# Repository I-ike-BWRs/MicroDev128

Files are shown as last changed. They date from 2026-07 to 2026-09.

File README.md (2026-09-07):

### *Thank You to PCBWay for sponsoring this project! To see more look up the "Sponsorship Section"*

---

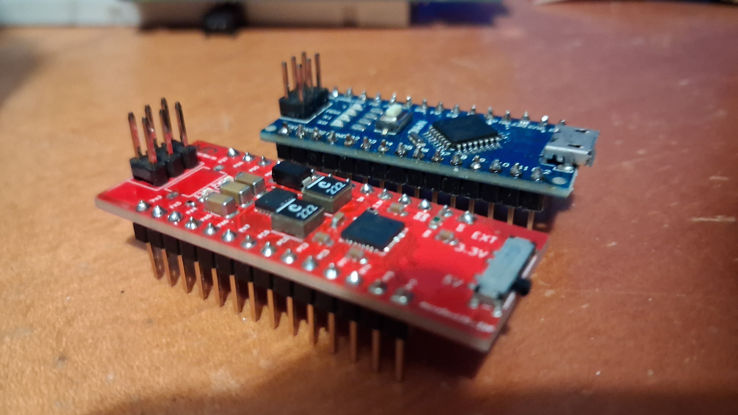
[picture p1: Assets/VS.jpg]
Project Image

# MicroDev128-32P
## A high-power development/prototyping board with MVIO. 

Based on the AVR128DB32. 

The MicroDev128-32P is open-source development board with a high-power voltage regulator with up to 2A continous, Multi-voltage IO - which allows PortC to run on a different voltage than the rest of the board - elimenating the need for voltage level shifters. The MicroDev128-32P aims to be better price to performance ratio than a tradition Arduino Nano. To view the Schematics you can go into the Kicad files folder. All files were made on KiCad 10.04 and should import without other dependencies. The 3D models are all included in the folder. 

**Key Specifications:**
- Up to 2A continuos on both power lines, 3.3v and 5v with up to 36VDC input
- Arduino Nano sized footprint, allowing it to easily be plugged into breadboards
- 128kB Flash, 16kB SRAM, and 512B
- Has with internal clock adjustable up to 24MHz max
- Built in TVS and 5A fuse
- UPDI Header for easy programing

## Documentation

For Documentation see the MicroDev128 Docs repository. 
[Link to Documents](https://github.com/ILikeBWRs/MicroDev128-Documentation)

---

## Images
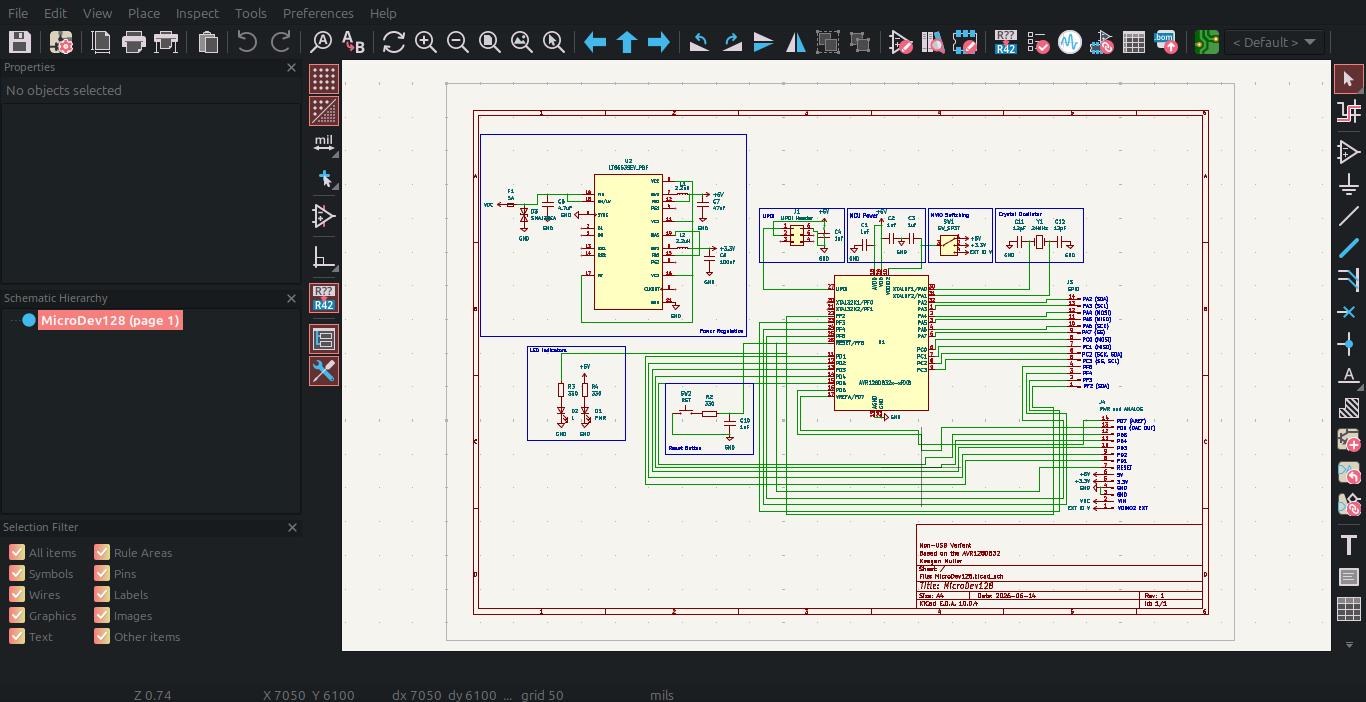
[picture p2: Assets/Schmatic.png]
Schematic

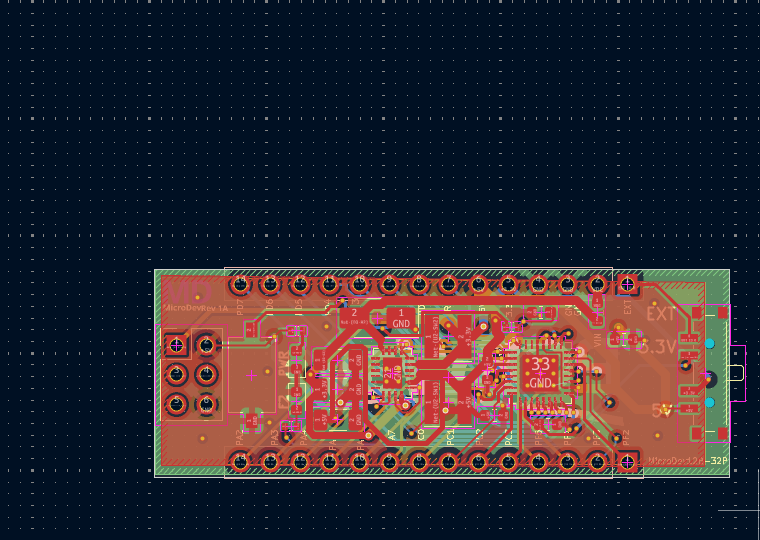
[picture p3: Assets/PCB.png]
PCB Layout

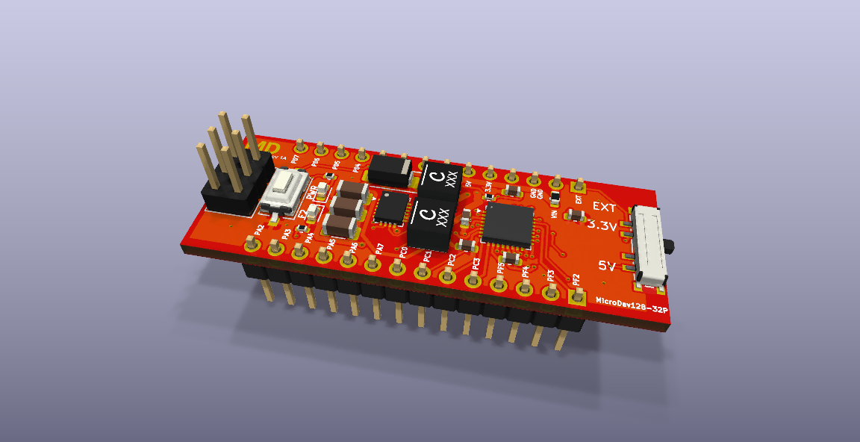
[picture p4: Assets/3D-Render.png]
3D Render


---

## Sponsorship
PCBway Logo
[PCBWay](https://pcbway.com) is a professional manufacturing service that offers PCB fabrication, PCB assembly, CNC machining, sheet metal fabrication, injection molding, and high-quality 3D printing services. They support a wide range of materials, including stainless steel, aluminum, titanium, and engineering plastics, making them suitable for prototype and production projects.
For my project they gave me five indivdual PCBs of outstanding surface quality. They surface was flat and smooth - with a perfect ENIG coating - with the corners rounded and deburred. The end application of this project is a Microcontroller board, suitable to be used in many situations. To see how easy their ordering procsess is go to the ordering section. 

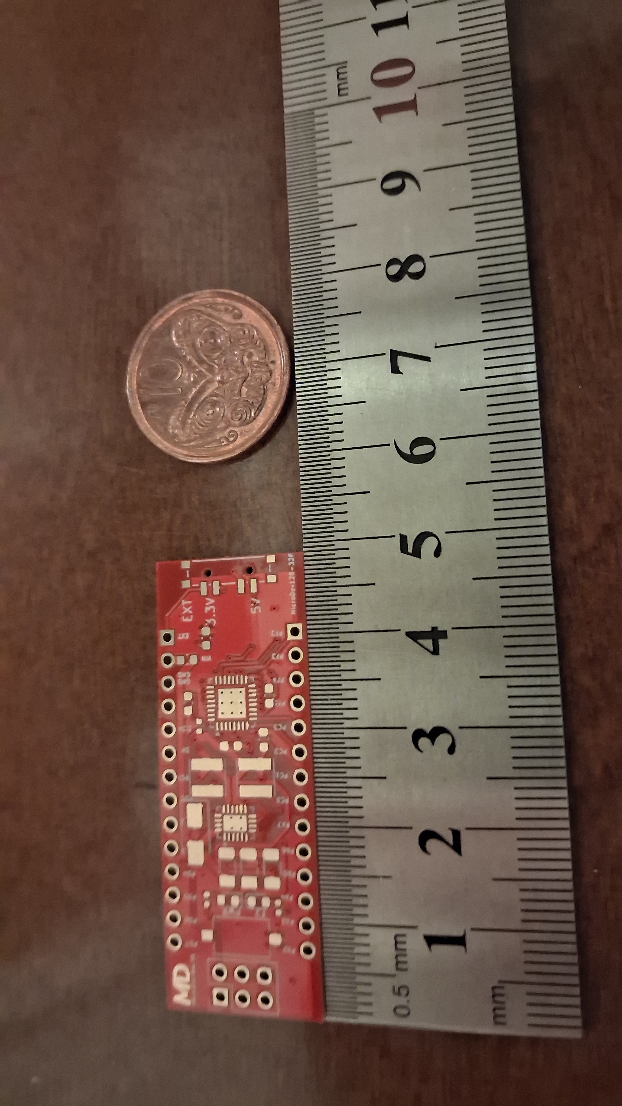
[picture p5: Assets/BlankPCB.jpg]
PCB


## Samples

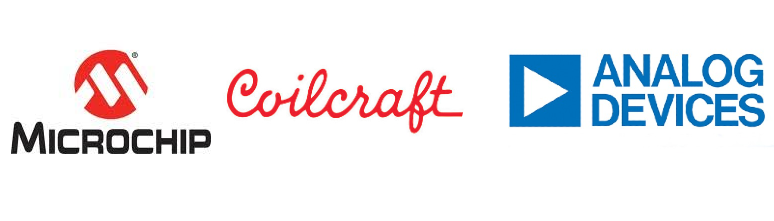
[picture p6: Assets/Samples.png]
Samples Companys


A big thank you to the sample programs of the following manufactures:
 - Microchip Technology
 - Analog Devices
 - Coilcraft
 - Würth Elektronik

---

## Ordering

To order your own you have a few ways:

**1. Order PCBs and assemble them yourself**

*You will need a hotplate for solder reflow and solder paste. May be cheaper but harder to do!*

Upload the Gebers at:
/MicroDev128-32P Production Files
   /Gebers.zip
Go to PCBWay's online ordering page and upload the gebers. Make sure it says 4-layers. Set it to ENIG, and set the solder mask to any colour you want. The rest of the default settings will be fine. Hit order or add stencil if you need one. It's that easy!

Next in the same folder find the BOM.csv and order the parts from your favorite part distributor. 
To lay out components once they turn up you can use the KiCad PCB layout. A dedicated image for this step will come later.

**2. Use PCBWay's PCBA service and get them shipped assembled**

Upload the Gebers at:

/Production Files

   /Gebers.zip
   
Go to your PCB and upload the gebers. Make sure it says 4-layers. Set it to ENIG, and set the solder mask to any colour you want. The default settings will be fine.
Then upload the BOM.csv and CPL.csv to the page. Then check if they in stock. (You may need to pre-order some parts!)
The check component orientation - it has a tendency to flip the LT8653S by 90 degrees. 
Then pay and let PCBWay's professional automated factory ship them fully assembled, right to your door!

## For more check out my stardance project page: -[Stardance Hackclub](https://stardance.hackclub.com/projects/6131)

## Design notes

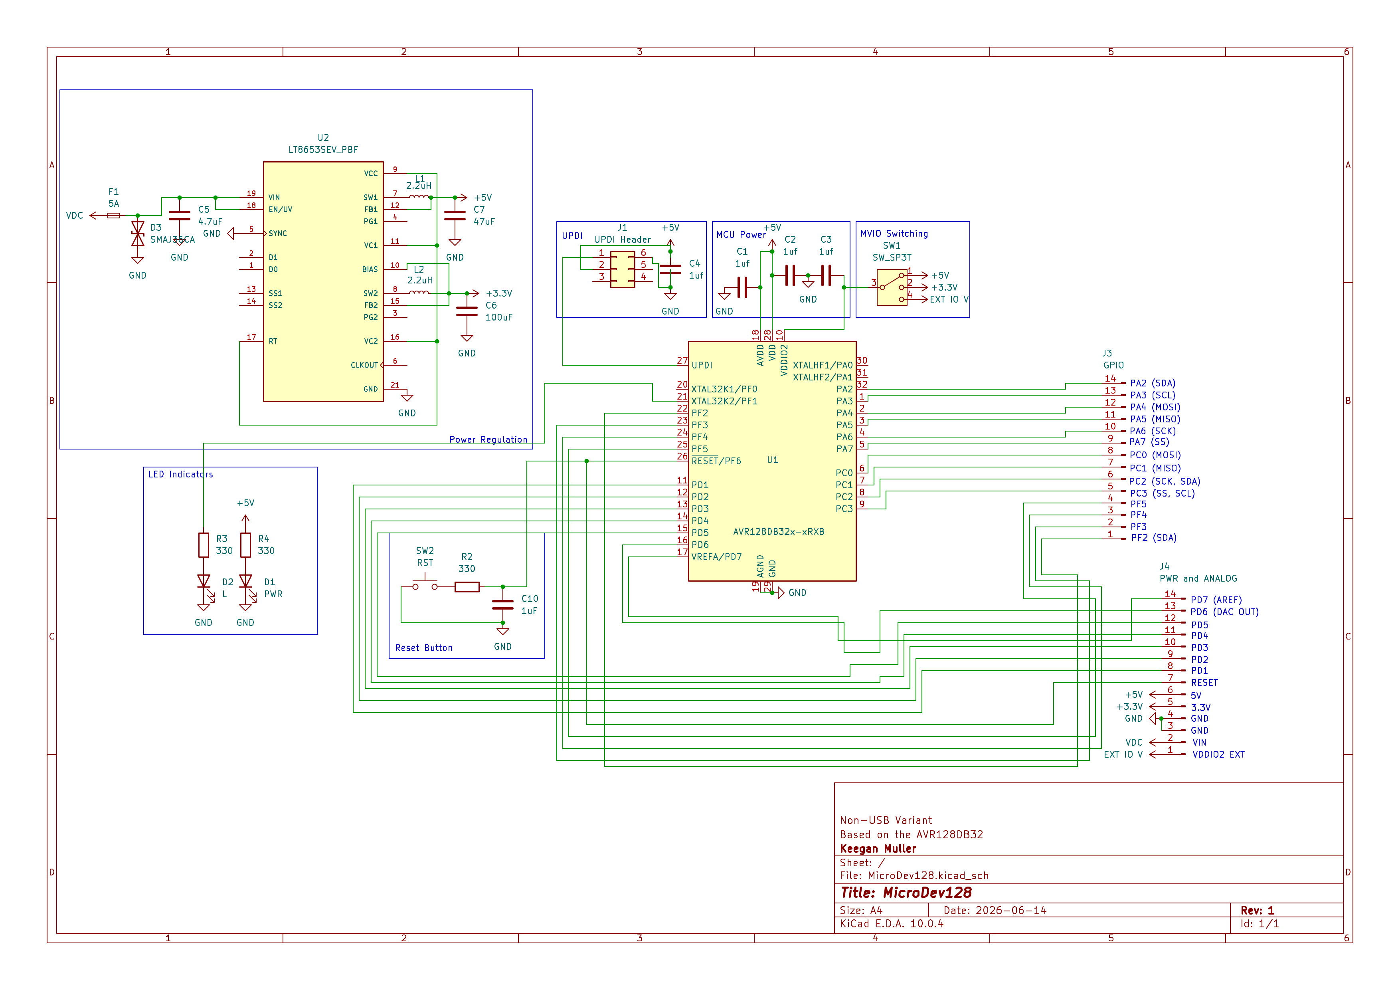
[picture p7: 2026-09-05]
Schematic.png

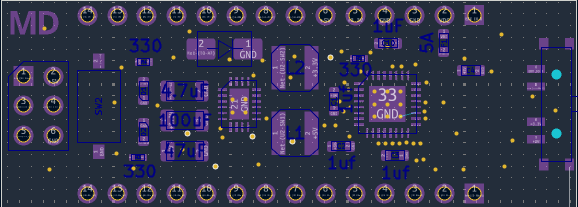
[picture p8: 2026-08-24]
MicroDev128-32P Production Files/Part Placement.png

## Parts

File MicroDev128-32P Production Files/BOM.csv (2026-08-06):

Reference | Value | Datasheet | Footprint | Qty | DNP
C1,C2,C3,C4 | 1uf |  | Capacitor_SMD:C_0603_1608Metric | 4
C5 | 4.7uF |  | Capacitor_SMD:C_1206_3216Metric | 1
C6 | 100uF |  | Capacitor_SMD:C_1206_3216Metric | 1
C7 | 47uF |  | Capacitor_SMD:C_1206_3216Metric | 1
C10 | 1uF |  | Capacitor_SMD:C_0603_1608Metric | 1
D1 | PWR |  | LED_SMD:LED_0603_1608Metric | 1
D2 | L |  | LED_SMD:LED_0603_1608Metric | 1
D3 | SMAJ36CA |  | Diode_SMD:D_SMA | 1
F1 | 5A |  | Fuse:Fuse_0603_1608Metric | 1
J1 | UPDI Header |  | Connector_PinHeader_2.54mm:PinHeader_2x03_P2.54mm_Vertical | 1
J3 | GPIO |  | Connector_PinHeader_2.54mm:PinHeader_1x14_P2.54mm_Vertical | 1
J4 | PWR and ANALOG |  | Connector_PinHeader_2.54mm:PinHeader_1x14_P2.54mm_Vertical | 1
L1,L2 | 2.2uH |  | Inductor_SMD:L_Taiyo-Yuden_NR-40xx | 2
R2,R3,R4 | 330 |  | Resistor_SMD:R_0402_1005Metric | 3
SW1 | SW_SP3T |  | Button_Switch_SMD:SW_SP3T_PCM13 | 1
SW2 | RST |  | Button_Switch_SMD:SW_Tactile_SPST_NO_Straight_CK_PTS636Sx25SMTRLFS | 1
U1 | AVR128DB32x-xRXB | https://ww1.microchip.com/downloads/en/DeviceDoc/AVR128DB28-32-48-64-DataSheet-DS40002247A.pdf | Package_DFN_QFN:QFN-32-1EP_5x5mm_P0.5mm_EP3.1x3.1mm | 1
U2 | LT8653SEV_PBF |  | Package_DFN_QFN:QFN-20-1EP_3x4mm_P0.5mm_EP1.65x2.65mm | 1

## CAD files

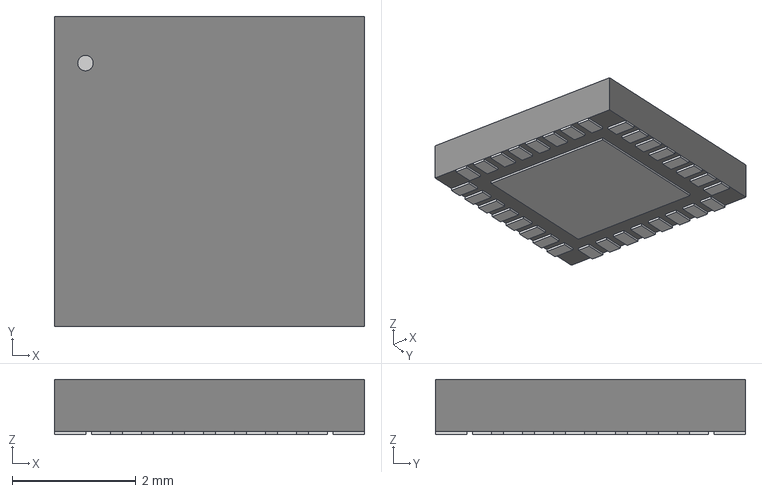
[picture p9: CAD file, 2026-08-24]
KiCad Files/3D Models/VQFN32_RXB_MCH.step
5.00 x 5.00 x 0.892 mm

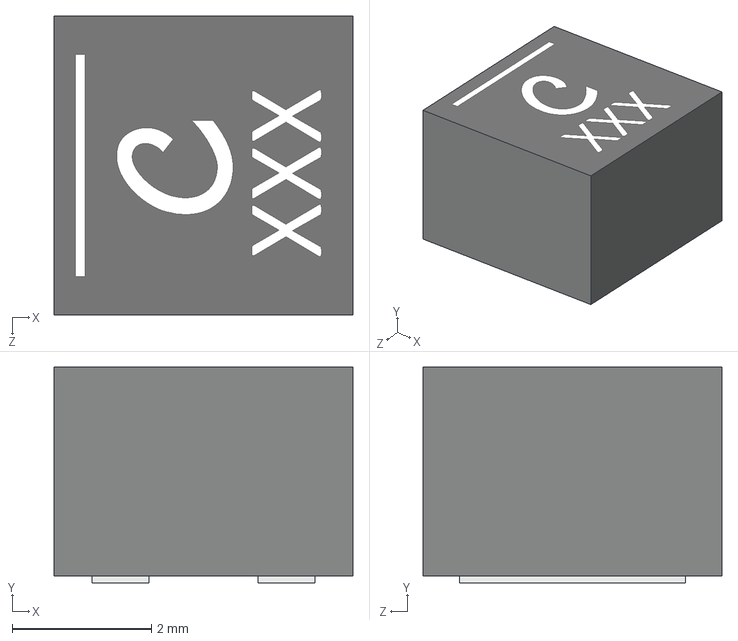
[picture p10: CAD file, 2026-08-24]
KiCad Files/3D Models/XGL4030.STEP
4.30 x 3.10 x 4.30 mm

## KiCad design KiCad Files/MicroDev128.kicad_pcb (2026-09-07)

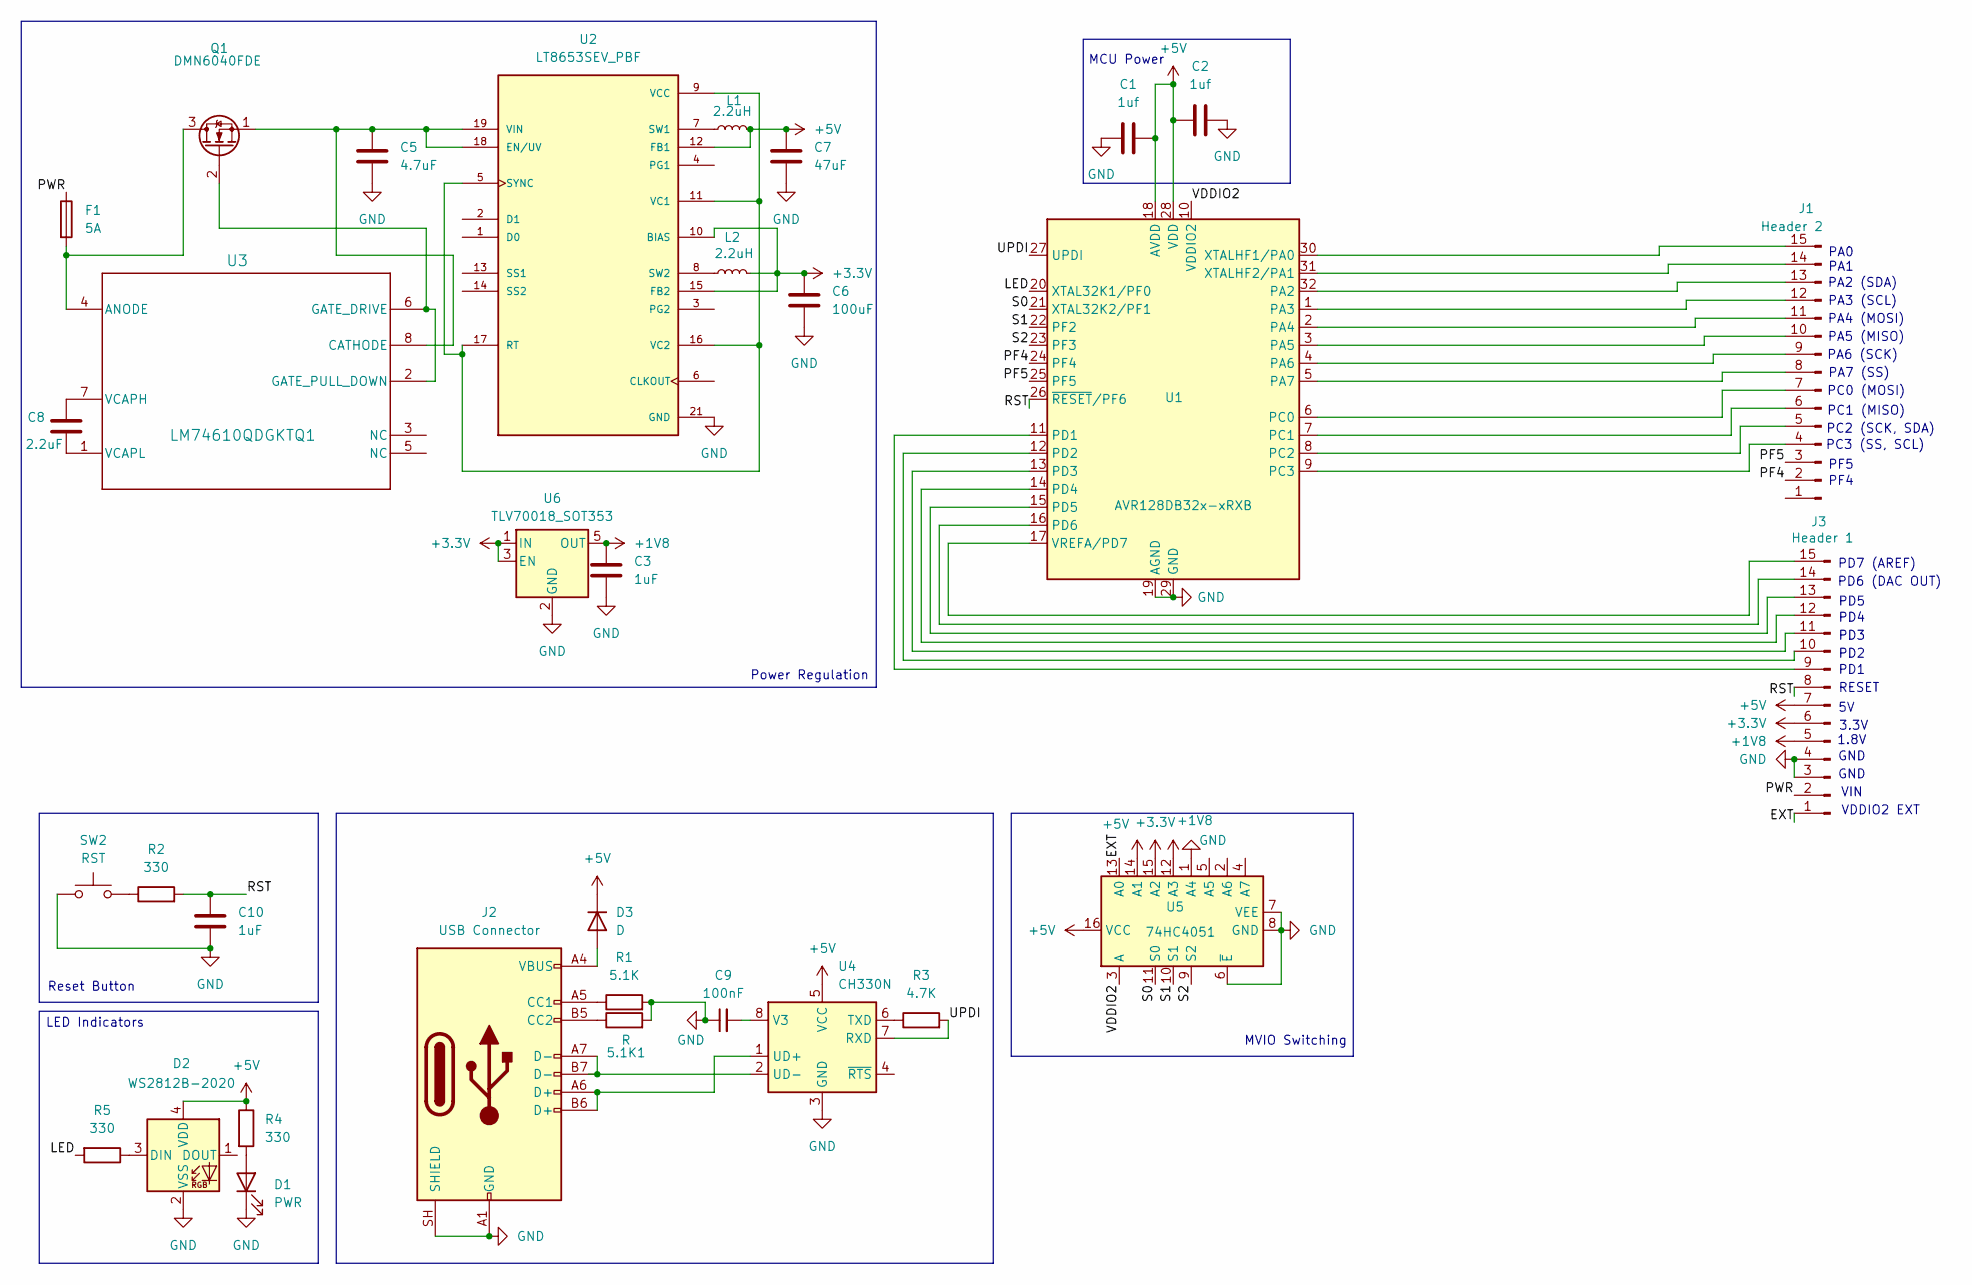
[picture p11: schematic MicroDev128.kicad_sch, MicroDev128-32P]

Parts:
5.1K1: R; R_0402_1005Metric
C1, C2: 1uf; C_0402_1005Metric
C3: 1uF; C_0402_1005Metric
C5: 4.7uF; C_1206_3216Metric
C6: 100uF; C_1206_3216Metric
C7: 47uF; C_1206_3216Metric
C8: 2.2uF; C_0402_1005Metric
C9: 100nF; C_0402_1005Metric
C10: 1uF; C_0603_1608Metric
D1: PWR; LED_0603_1608Metric
D2: WS2812B-2020; LED_WS2812B-2020_PLCC4_2.0x2.0mm
D3: D; D_SOD-323
F1: 5A; Fuse_0603_1608Metric
J1: Header 2; PinHeader_1x15_P2.54mm_Vertical
J2: USB Connector; USB_C_Receptacle_HRO_TYPE-C-31-M-12
J3: Header 1; PinHeader_1x15_P2.54mm_Vertical
L1, L2: 2.2uH; L_Taiyo-Yuden_NR-40xx
Q1: DMN6040FDE; DFN-6-1EP_2x2mm_P0.65mm_EP1.01x1.7mm
R1: 5.1K; R_0402_1005Metric
R2, R4, R5: 330; R_0402_1005Metric
R3: 4.7K; R_0402_1005Metric
SW2: RST; SW_Tactile_SPST_NO_Straight_CK_PTS636Sx25SMTRLFS
U1: AVR128DB32x-xRXB; QFN-32-1EP_5x5mm_P0.5mm_EP3.1x3.1mm
U2: LT8653SEV_PBF; QFN-20-1EP_3x4mm_P0.5mm_EP1.65x2.65mm; PARTREV B
U3: LM74610QDGKTQ1; VSSOP-8_3x3mm_P0.65mm
U4: CH330N; SOIC-8_3.9x4.9mm_P1.27mm
U5: 74HC4051; DHVQFN-16-1EP_2.5x3.5mm_P0.5mm_EP1x2mm
U6: TLV70018_SOT353; SOT-353_SC-70-5

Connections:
+1V8: C3.1, J3.5, U5.12 (A3), U6.5 (OUT)
+3.3V: C6.1, J3.6, L2.2, U2.10 (BIAS), U2.15 (FB2), U5.15 (A2), U6.1 (IN), U6.3 (EN)
+5V: C1.2, C2.1, C7.1, D2.4 (VDD), D3.1 (K), J3.7, L1.2, R4.1, U1.18 (AVDD), U1.28 (VDD), U2.12 (FB1), U4.5 (VCC), U5.14 (A1), U5.16 (VCC)
/EXT: J3.1, U5.13 (A0)
/LED: R5.2, U1.20 (XTAL32K1/PF0)
/PF4: J1.2, U1.24 (PF4)
/PF5: J1.3, U1.25 (PF5)
/PWR: F1.1, J3.2
/RST: C10.1, J3.8, R2.2, U1.26 (~RESET/PF6)
/S0: U1.21 (XTAL32K2/PF1), U5.11 (S0)
/S1: U1.22 (PF2), U5.10 (S1)
/S2: U1.23 (PF3), U5.9 (S2)
/UPDI: R3.2, U1.27 (UPDI), U4.7 (RXD)
/VDDIO2: U1.10 (VDDIO2), U5.3 (A)
GND: 5.1K1.2, C1.1, C2.2, C3.2, C5.2, C6.2, C7.2, C9.1, C10.2, D1.1 (K), D2.2 (VSS), J2.A1 (GND), J2.A12 (GND), J2.B1 (GND), J2.B12 (GND), J2.SH (SHIELD), J3.3, J3.4, R1.2, SW2.1, U1.19 (AGND), U1.29 (GND), U1.33 (GND), U2.21 (GND), U4.3 (GND), U5.1 (A4), U5.6 (~E), U5.7 (VEE), U5.8 (GND), U6.2 (GND)
unnamed: D1.2 (A), R4.2
unnamed: D2.3 (DIN), R5.1
unnamed: D3.2 (A), J2.A4 (VBUS), J2.A9 (VBUS), J2.B4 (VBUS), J2.B9 (VBUS)
unnamed: J1.4, U1.9 (PC3)
unnamed: J1.5, U1.8 (PC2)
unnamed: J1.6, U1.7 (PC1)
unnamed: J1.7, U1.6 (PC0)
unnamed: J1.8, U1.5 (PA7)
unnamed: J1.9, U1.4 (PA6)
unnamed: J1.10, U1.3 (PA5)
unnamed: J1.11, U1.2 (PA4)
unnamed: J1.12, U1.1 (PA3)
unnamed: J1.13, U1.32 (PA2)
unnamed: J1.14, U1.31 (XTALHF2/PA1)
unnamed: J1.15, U1.30 (XTALHF1/PA0)
unnamed: J2.A5 (CC1), R1.1
unnamed: 5.1K1.1, J2.B5 (CC2)
unnamed: J3.9, U1.11 (PD1)
unnamed: J3.10, U1.12 (PD2)
unnamed: J3.11, U1.13 (PD3)
unnamed: J3.12, U1.14 (PD4)
unnamed: J3.13, U1.15 (PD5)
unnamed: J3.14, U1.16 (PD6)
unnamed: J3.15, U1.17 (VREFA/PD7)
unnamed: F1.2, Q1.3 (D), U3.4 (ANODE)
unnamed: Q1.2 (G), U3.2 (GATE_PULL_DOWN), U3.6 (GATE_DRIVE)
unnamed: C5.1, Q1.1 (S), U2.18 (EN/UV), U2.19 (VIN), U2.20 (VIN), U3.8 (CATHODE)
unnamed: R2.1, SW2.2
unnamed: U2.5 (SYNC), U2.9 (VCC), U2.11 (VC1), U2.16 (VC2), U2.17 (RT)
unnamed: L1.1, U2.7 (SW1)
unnamed: L2.1, U2.8 (SW2)
unnamed: C8.1, U3.7 (VCAPH)
unnamed: C8.2, U3.1 (VCAPL)
unnamed: R3.1, U4.6 (TXD)
unnamed: J2.A6 (D+), J2.B6 (D+), U4.1 (UD+)
unnamed: J2.A7 (D-), J2.B7 (D-), U4.2 (UD-)
unnamed: C9.2, U4.8 (V3)

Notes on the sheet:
PD5
PC2 (SCK, SDA)
LED Indicators
GND
PA5 (MISO)
3.3V
PD3
Reset Button
PF4
PA7 (SS)
PC0 (MOSI)
PD2
VIN
PA1
PA0
PA4 (MOSI)
1.8V
RESET
PD6 (DAC OUT)
PF5
PA2 (SDA)
Power Regulation
PA6 (SCK)
PC1 (MISO)
MVIO Switching
VDDIO2 EXT
PD7 (AREF)
PA3 (SCL)
PD1
PC3 (SS, SCL)
PD4
MCU Power
GND

Board: 4 copper layers, 32 parts (2 on the bottom side), 52 nets, no tracks yet.

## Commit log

2026-07-25 INITIAL COMMIT
    Just adding the files
    [BOM.csv, MicroDev128 (AVR128DB28).kicad_sch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]
2026-07-25 Update to clarift Costs and fix errors
    [BOM.csv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]
2026-07-25 Fix schematic image filename in README
    Corrected the filename of the schematic image in the README.
2026-07-31 Added PCB Guide and hackclub link
2026-08-03 Updates for PCB and SPONOSER
    [MicroDev128-B_Cu.gbl, MicroDev128-B_Mask.gbs, MicroDev128-B_Silkscreen.gbo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]
2026-08-04 Updated for sponsor
    [MicroDev128-B_Cu.gbl, MicroDev128-B_Mask.gbs, MicroDev128-B_Silkscreen.gbo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]
2026-08-06 Updated For PCB Update
    [BOM.csv, FUNDING (Hack Club).csv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]
2026-08-24 Updated Files For models
    Also added some small fixes
    [MicroDev128.kicad_pcb, MicroDev128.kicad_sch, VQFN32_RXB_MCH.step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]
2026-08-24 updated Images
    [MicroDev128.kicad_pcb]
2026-08-25 Trimmed files and updated sponsorship
    [FUNDING (Hack Club).csv]
2026-08-25 Trimmed repo
    [MicroDev128 (AVR128DB28).kicad_sch]
2026-08-25 Added PCBWay link
2026-08-26 Fixed PCBWay title
2026-08-26 Updated PCBWay terms
2026-08-26 Fixed PCBWay name
2026-09-05 Updated PCB, fixed errors, and added more docs
    [MicroDev128.kicad_pcb, MicroDev128.kicad_sch]
2026-09-05 Started on Rev1B
    [MicroDev128.kicad_sch]
2026-09-07 Updated Naming, and started in dev work
    On rev 1B
    [MicroDev128.kicad_pcb, MicroDev128.kicad_sch]
